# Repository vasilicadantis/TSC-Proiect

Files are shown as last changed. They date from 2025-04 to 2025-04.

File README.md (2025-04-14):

# OpenBook

Vasilica Danțiș – 332CD

## Diagrama bloc


## BOM

| Componenta | Link |
| ---| ---|
| led | [Link](https://www.snapeda.com/parts/KP-1608SURCK/Kingbright/view-part/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) |
| Button_customv1 | [Link](https://industry.panasonic.com/global/en/products/control/switch/light-touch/number/evqpuj02k) |
| Eagle_ltspice_c | [Link](https://componentsearchengine.com/part-view/0402WGF3001TCE/UNI-ROYAL(Uniroyal%20Elec)) |
| ESP32_WROVER_AVX—SD0805S020S1R0 | [Link](https://ro.mouser.com/ProductDetail/KYOCERA-AVX/SD0805S020S1R0?qs=jCA%252BPfw4LHbpkAoSnwrdjw%3D%3D) |
| ESP32_WROVER_BME680_BME680 | [Link](https://www.snapeda.com/parts/BME680/Bosch/view-part/?welcome=home) |
| ESP32_WROVER_EAGLE-LTSPICE_R | [Link](https://componentsearchengine.com/part-view/R0402%201%25%20100%20K%20(RC0402FR-07100KL)/YAGEO) |
| RCL_CPOL-EU | [Link](https://www.snapeda.com/parts/TAJB475K025RNJ/AVX/view-part/?t=capacitor%203528&con_ref=None) |
| SJ | [Link](https://grabcad.com/library/solder-jumpers-1) |
| R-URI | [Link](https://componentsearchengine.com/part-view/R0402%201%25%20100%20K%20(RC0402FR-07100KL)/YAGEO) |
| ESP32_WROVER_SPARKFUN-DISCRETESEMI_MOSFET_PCH | [Link](https://componentsearchengine.com/part-view/DMG2305UX-7/Diodes%20Incorporated) |
| ESP32_WROVER_SPARKFUN-IC-POWER_MCP73831 | [Link](https://eu.mouser.com/ProductDetail/Microchip-Technology/MCP73831T-2ACI-OT?qs=yUQqVecv4qvbBQBGbHx0Mw%3D%3D) |
| TP | Facut Manual (un cilindru) |
| FH34SRJ-24S-0.5SH_99_ | [Link](https://componentsearchengine.com/part-view/FH34SRJ-24S-0.5SH(99)/Hirose) |
| MAX17048G+T10 | [Link](https://www.snapeda.com/parts/MAX17048G+T10/Analog+Devices/view-part/) |
| SAMACSYS_PARTS_USB4110-GF-A | [Link](https://componentsearchengine.com/part-view/USB4110-GF-A/GCT%20(GLOBAL%20CONNECTOR%20TECHNOLOGY)) |
| QWIIC_CONNECTOR | [Link](https://www.snapeda.com/parts/PRT-14417/SparkFun%20Electronics/view-part/?t=QWIIC_CONNECTORJS-1MM) |
| 112A-TAAR-R03_ATTEND | [Link](https://componentsearchengine.com/part-view/112A-TAAR-R03%20ATTEND/ATTEND) |
| 744043680IND_4828-WE-TPC_WRE | [Link](https://componentsearchengine.com/part-view/744043680/W%C3%BCrth%20Elektronik) |
| BD5229G-TR | [Link](https://componentsearchengine.com/part-view/BD5229G-TR/ROHM%20Semiconductor) |
| CPH3225A | [Link](https://componentsearchengine.com/part-view/CPH3225A/Seiko%20Semiconductors) |
| DS3231SN# | [Link](https://componentsearchengine.com/part-view/DS3231SN%23/Analog%20Devices) |
| ESP32-C6-WROOM-1-N8 | [Link](https://componentsearchengine.com/part-view/ESP32-C6-WROOM-1-N8/Espressif%20Systems) |
| MBR0530 | [Link](https://componentsearchengine.com/part-view/MBR0530/onsemi) |
| SI1308EDL-T1-GE3 | [Link](https://componentsearchengine.com/part-view/SI1308EDL-T1-GE3/Vishay) |
| USBLC6-2SC6Y | [Link](https://componentsearchengine.com/part-view/USBLC6-2SC6Y/STMicroelectronics) |
| W25Q512JVEIQ | [Link](https://componentsearchengine.com/part-view/W25Q512JVEIQ/Winbond) |
| XC6220A331MR-G | [Link](https://componentsearchengine.com/part-view/XC6220A331MR-G/Torex) |

## Descriere detaliată a funcționalității hardware

1. **Microcontroller (ESP32-C6)**
   - **Rol:** Asigură controlul central al dispozitivului, conectivitatea Wi-Fi, logica de afișare pe E-Ink și interfața cu utilizatorul (butoane).
   - **Caracteristici:**
     - Integrează un nucleu RISC-V și un subsistem Wi-Fi 6 (802.11ax).
     - Consum redus în modurile de *deep-sleep*, esențial pentru un e-book reader.

2. **E-Ink Display**
   - **Tip:** (ex.) 2.9" EPD (monocrom), cu driver intern sau driver separat.
   - **Interfață cu ESP32-C6:** SPI (poate fi 4-wire SPI cu linii de comandă suplimentare: DC, CS, RST, BUSY).
   - **Motiv:** E-Ink-ul are consum redus de energie, menținând imaginea chiar și fără alimentare (refresh scăzut).

3. **Senzor BME688**
   - **Rol:** Permite ajustarea luminozității (dacă există LED) sau stocarea datelor de mediu.
   - **Interfață:** I2C (implicit) / SPI (opțional).
   - **Consum:** Relativ mic (în jur de câțiva µA în mod de stand-by, dar poate crește la câteva mA în mod de funcționare continuă).

4. **DS3231 RTC**
   - **Rol:** Asigură un ceas de timp real foarte precis, cu consum scăzut.
   - **Interfață:** I2C, cu eventual pin de interrupt (INT/SQW) pentru semnal periodic sau alarmă.
   - **Consum:** Aproximativ 1-2 µA în modul de menținere a ceasului (alimentat direct din baterie).

5. **Memorie externă NOR Flash (W25Q512)**
   - **Rol:** Oferă stocare suplimentară (ex. 64Mbit) pentru fișiere, resurse, cărți electronice etc.
   - **Interfață:** SPI la viteze ridicate (până la 40-80MHz, dacă e specificat).
   - **Consum:** Câțiva mA în scriere/citire și µA în mod standby.

6. **Sistem de alimentare și managementul bateriei**
   - **USB-C Connector:** Permite alimentare la 5V și date (pentru programare/debug).
   - **Battery Charger (MCP73831):** Încarcă Li-Po la 4.2V cu un curent setat prin rezistență PROG (ex. 500mA).
   - **LDO / DC-DC:** Convertește tensiunea bateriei (3.7V nominal) în 3.3V stabil pentru ESP32-C6, E-Ink și restul circuitelor. Dacă se dorește extragerea tensiunii de 5V, se poate folosi un boost converter (DC-DC step-up).
   - **Calcul consum (approx.):**
     - **ESP32-C6:** ~80-240 mA în mod Tx Wi-Fi, <1 mA în modem-sleep, câțiva µA în deep-sleep.
     - **E-Ink:** Consum ridicat doar la refresh (~tens of mA), inactiv aproape 0.
     - **Senzor BME688:** <1 mA tipic (pe I2C) în mod standard, <1 µA în stand-by.
     - **RTC DS3231:** 1-2 µA pentru menținerea ceasului.

7. **Interfața utilizator (Butoane)**
   - 3 butoane SMD (ex. Boot, Change, Reset) conectate la pinii GPIO ai ESP32-C6, cu rezistențe de pull-up/pull-down și debounce minimal (sau software).

8. **Alte considerații**
   - Protecție ESD pe USB, liniile SPI, conectori externi.
   - Test pad-uri: Semnalele principale (MISO, MOSI, RX, GND) expuse pentru programare / debugging.

## Detalii despre pinii ESP32-C6



## Considerații de design PCB

### Rutarea traseelor de alimentare
- Lățime de minimum **0.3 mm** pentru liniile de putere (3V3, 5V, VBAT).
- Lățime de minimum **0.15 mm** pentru liniile de date (SPI, I2C, UART etc.).
- Grosime PCB de maximum **1 mm** pentru a încăpea în carcasă.

### Decuplare
- Condensatoare de **100 nF (0402)** lângă fiecare pin de alimentare al circuitelor integrate (ESP32, BME688, DS3231, Flash).
- Condensatoare mai mari (ex. **4.7 µF ~ 10 µF**) pentru stabilizarea surselor locale.

### Antenă ESP32-C6
- Zona antenei trebuie eliberată de planul de masă și semnale, cu decupaj PCB sub antenă.

### DRC și ERC
- Verificarea regulilor de design: evitarea unghiurilor de 90°; utilizarea via stitching pe planul GND; respectarea reglementărilor de clearance etc.

### Placement
- Componentele SMD sunt plasate exclusiv pe **Top Layer** (conform specificațiilor proiectului).
- Butoanele sunt poziționate ergonomic pentru utilizator.
- Conectorul USB-C este accesibil pe marginea plăcii.

### Via Stitching
- Implementat în jurul ESP32-C6 și al planului de masă pentru reducerea zgomotului EMI.

### Test pad-uri
- Semnalele MISO, MOSI, SCK, GND, 3V3, TX, RX etc. sunt accesibile pentru programare și debugging.

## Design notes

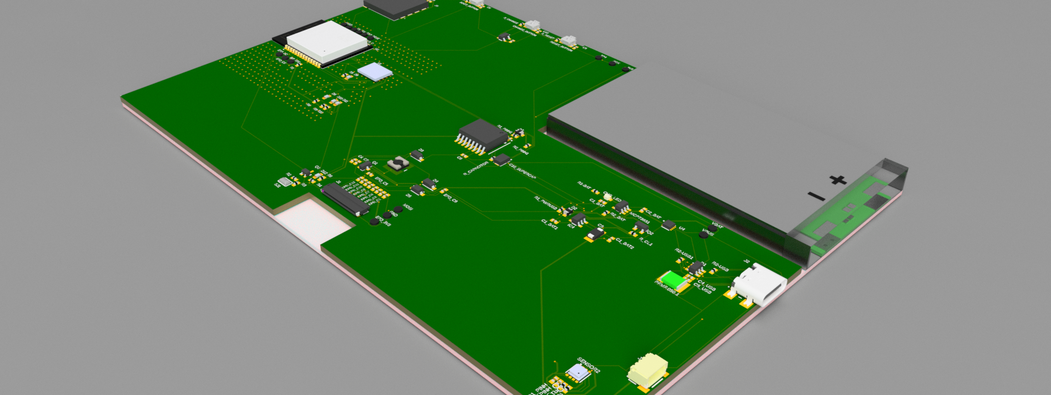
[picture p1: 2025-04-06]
Images/Battery + PCB.png

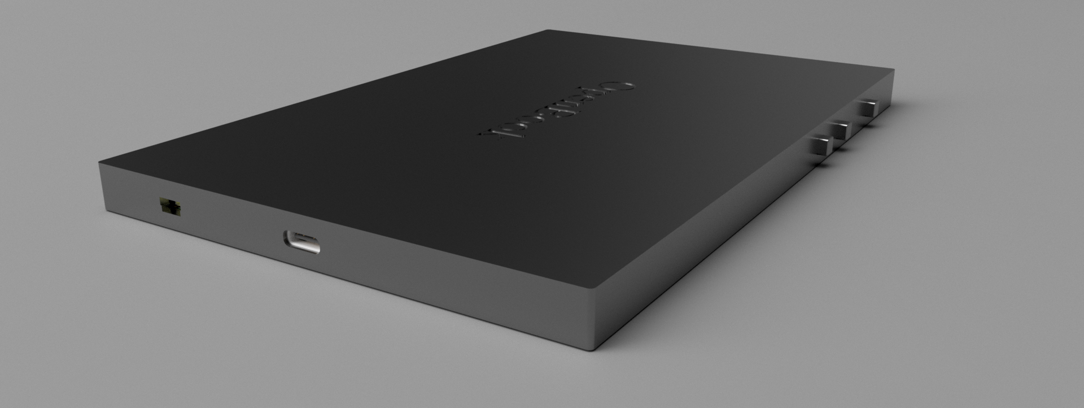
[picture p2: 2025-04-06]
Images/OpenBook - back.png

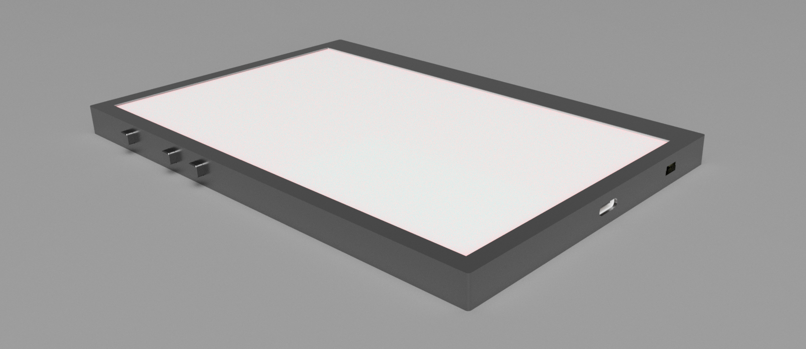
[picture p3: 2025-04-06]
Images/OpenBook - front.png

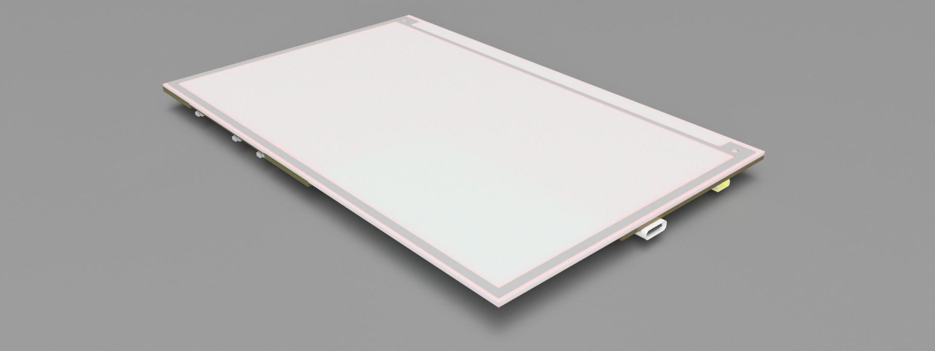
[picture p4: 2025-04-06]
Images/Display.png

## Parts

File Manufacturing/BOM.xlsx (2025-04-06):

Qty | Value | Device | Package | Parts | Description | ARROW_PART_NUMBER | ARROW_PRICE-STOCK | AVAILABILITY | CENTROID_NOT_SPECIFIED | CHECK_PRICES | COPYRIGHT | DATASHEET | DESCRIPTION | DIGIKEY_DESCRIPTION | DIGIKEY_PART_NUMBER | HEIGHT | LEAD_FREE | MANUFACTURER_NAME | MANUFACTURER_PART_NUMBER | MF | MFR_NAME | MOUSER_PART_NUMBER | MOUSER_PRICE-STOCK | MOUSER_TESTING_PART_NUMBER | MOUSER_TESTING_PRICE-STOCK | MP | MPN | PACKAGE | POPULARITY | PREFIX | PRICE | PROD_ID | PURCHASE-URL | ROHS | SNAPEDA_LINK | SPICEMODEL | SPICEPREFIX | TEMPERATURE_RANGE_HIGH | TEMPERATURE_RANGE_LOW | TP_SIGNAL_NAME | VALUE
1 |  | ADAFRUIT_LEDCHIP-LED0603 | ADAFRUIT_CHIP-LED0603 | CHG_LED | LED
1 |  | SJ | SJ | SJ1 | SMD solder JUMPER |  |  |  |  |  |  |  |  |  |  |  |  |  |  |  |  |  |  |  |  |  |  |  | 3
1 | 0.47 | ESP32_WROVER_EAGLE-LTSPICE_RR0402 | ESP32_WROVER_EAGLE-LTSPICE_R0402 | R3 | RESISTOR, European symbol |  |  |  |  |  |  |  |  |  |  |  |  |  |  |  |  |  |  |  |  |  |  |  |  |  |  |  |  |  |  | NONE | R
1 | 100K | ESP32_WROVER_EAGLE-LTSPICE_RR0402 | ESP32_WROVER_EAGLE-LTSPICE_R0402 | R1_PWRUSB | RESISTOR, European symbol |  |  |  |  |  |  |  |  |  |  |  |  |  |  |  |  |  |  |  |  |  |  |  |  |  |  |  |  |  |  | NONE | R
8 | 100nF | ESP32_WROVER_EAGLE-LTSPICE_CC0402 | ESP32_WROVER_EAGLE-LTSPICE_C0402 | C1, C2, C4_USB, C6, C8, C9, C10, C_DELAY | CAPACITOR, European symbol |  |  |  |  |  |  |  |  |  |  |  |  |  |  |  |  |  |  |  |  |  |  |  |  |  |  |  |  |  |  | NONE | C
1 | 100uF | RCL_CPOL-EUCT3528 | RCL_CT3528 | C3 | POLARIZED CAPACITOR, European symbol |  |  |  |  |  |  |  |  |  |  |  |  |  |  |  |  |  |  |  |  |  |  |  | 0 |  |  |  |  |  |  |  | C
14 | 10K | ESP32_WROVER_EAGLE-LTSPICE_RR0402 | ESP32_WROVER_EAGLE-LTSPICE_R0402 | R1_PINH, R1_PINH1, R2_PINH, R2_PINH1, R5, R6, R7, R8, R9, R10, R_BOOT, R_CHANGE, R_CL1, R_RESET | RESISTOR, European symbol |  |  |  |  |  |  |  |  |  |  |  |  |  |  |  |  |  |  |  |  |  |  |  |  |  |  |  |  |  |  | NONE | R
2 | 10k | ESP32_WROVER_EAGLE-LTSPICE_RR0402 | ESP32_WROVER_EAGLE-LTSPICE_R0402 | R1, R4 | RESISTOR, European symbol |  |  |  |  |  |  |  |  |  |  |  |  |  |  |  |  |  |  |  |  |  |  |  |  |  |  |  |  |  |  | NONE | R
1 | 10uF | ESP32_WROVER_EAGLE-LTSPICE_CC0402 | ESP32_WROVER_EAGLE-LTSPICE_C0402 | C7 | CAPACITOR, European symbol |  |  |  |  |  |  |  |  |  |  |  |  |  |  |  |  |  |  |  |  |  |  |  |  |  |  |  |  |  |  | NONE | C
1 | 112A-TAAR-R03_ATTEND | 112A-TAAR-R03_ATTEND | 112ATAARR03ATTEND | J4 | Micro SD Card Socket, Push-Push Type, Top Mount, SMT, H=1.83mm, 10u |  |  |  |  |  |  |  | Micro SD Card Socket | Push-Push Type | Top Mount | SMT | H=1.83mm | 10u |  |  | 1.9mm |  | ATTEND | 112A-TAAR-R03 ATTEND
1 | 15 | ESP32_WROVER_EAGLE-LTSPICE_RR0402 | ESP32_WROVER_EAGLE-LTSPICE_R0402 | R_CAPACITOR | RESISTOR, European symbol |  |  |  |  |  |  |  |  |  |  |  |  |  |  |  |  |  |  |  |  |  |  |  |  |  |  |  |  |  |  | NONE | R
1 | 1uF | ESP32_WROVER_EAGLE-LTSPICE_CC0402 | ESP32_WROVER_EAGLE-LTSPICE_C0402 | C5 | CAPACITOR, European symbol |  |  |  |  |  |  |  |  |  |  |  |  |  |  |  |  |  |  |  |  |  |  |  |  |  |  |  |  |  |  | NONE | C
10 | 1uF/50V | ESP32_WROVER_EAGLE-LTSPICE_CC0402 | ESP32_WROVER_EAGLE-LTSPICE_C0402 | EPD_C1, EPD_C2, EPD_C5, EPD_C6, EPD_C7, EPD_C8, EPD_C9, EPD_C10, EPD_C11, EPD_C12 | CAPACITOR, European symbol |  |  |  |  |  |  |  |  |  |  |  |  |  |  |  |  |  |  |  |  |  |  |  |  |  |  |  |  |  |  | NONE | C
1 | 2.2 | ESP32_WROVER_EAGLE-LTSPICE_RR0402 | ESP32_WROVER_EAGLE-LTSPICE_R0402 | R2 | RESISTOR, European symbol |  |  |  |  |  |  |  |  |  |  |  |  |  |  |  |  |  |  |  |  |  |  |  |  |  |  |  |  |  |  | NONE | R
1 | 200 | ESP32_WROVER_EAGLE-LTSPICE_RR0402 | ESP32_WROVER_EAGLE-LTSPICE_R0402 | R1-BAT | RESISTOR, European symbol |  |  |  |  |  |  |  |  |  |  |  |  |  |  |  |  |  |  |  |  |  |  |  |  |  |  |  |  |  |  | NONE | R
2 | 20V/4.2A/52mO/1.4W | ESP32_WROVER_SPARKFUN-DISCRETESEMI_MOSFET_PCH-DMG2305UX-7 | ESP32_WROVER_SPARKFUN-DISCRETESEMI_SOT23-3 | Q1, Q2 | P-channel MOSFETs |  |  |  |  |  |  |  |  |  |  |  |  |  |  |  |  |  |  |  |  |  |  |  |  |  |  | TRAN-14388 |  |  |  |  |  |  |  |  | 20V/4.2A/52mO/1.4W
1 | 2K | ESP32_WROVER_EAGLE-LTSPICE_RR0402 | ESP32_WROVER_EAGLE-LTSPICE_R0402 | R2_BAT | RESISTOR, European symbol |  |  |  |  |  |  |  |  |  |  |  |  |  |  |  |  |  |  |  |  |  |  |  |  |  |  |  |  |  |  | NONE | R
1 | 4.7UF | ESP32_WROVER_EAGLE-LTSPICE_CC0402 | ESP32_WROVER_EAGLE-LTSPICE_C0402 | C2_BAT | CAPACITOR, European symbol |  |  |  |  |  |  |  |  |  |  |  |  |  |  |  |  |  |  |  |  |  |  |  |  |  |  |  |  |  |  | NONE | C
4 | 4.7uF | ESP32_WROVER_EAGLE-LTSPICE_CC0402 | ESP32_WROVER_EAGLE-LTSPICE_C0402 | C1_BAT, C1_BAT1, C1_BAT2, C5_USB | CAPACITOR, European symbol |  |  |  |  |  |  |  |  |  |  |  |  |  |  |  |  |  |  |  |  |  |  |  |  |  |  |  |  |  |  | NONE | C
1 | 4.7uF/25V | ESP32_WROVER_EAGLE-LTSPICE_CC0402 | ESP32_WROVER_EAGLE-LTSPICE_C0402 | C4 | CAPACITOR, European symbol |  |  |  |  |  |  |  |  |  |  |  |  |  |  |  |  |  |  |  |  |  |  |  |  |  |  |  |  |  |  | NONE | C
2 | 5K1 | ESP32_WROVER_EAGLE-LTSPICE_RR0402 | ESP32_WROVER_EAGLE-LTSPICE_R0402 | R2-USB, R2-USB1 | RESISTOR, European symbol |  |  |  |  |  |  |  |  |  |  |  |  |  |  |  |  |  |  |  |  |  |  |  |  |  |  |  |  |  |  | NONE | R
1 | 68uH | 744043680IND_4828-WE-TPC_WRE | IND_4828-WE-TPC_WRE | L1 |  |  |  |  |  |  | Copyright (C) 2024 Ultra Librarian. All rights reserved. |  |  |  |  |  |  |  | 744043680 |  | Wurth Electronics
1 | BD5229G-TR | BD5229G-TR | SOT95P280X120-5N | IC1 | Voltage Detector with Adjustable Delay Time: CMOS processes are utilized to develop high precision, low current consumption CMOS reset ICs that allow arbitrary setting of the delay time. The extensive lineup includes both Nch Open Drain and CMOS output types in a wide range of detection voltages (from 2.3V to 6.0V, in 0.1V steps), enabling selection of the ideal solution based on customer requirements. In addition, the entire series is of course both lead-free and RoHS-compliant. |  |  |  |  |  |  |  | Voltage Detector with Adjustable Delay Time: CMOS processes are utilized to develop high precision | low current consumption CMOS reset ICs that allow arbitrary setting of the delay time. The extensive lineup includes both Nch Open Drain and CMOS output types in a wide range of detection voltages (from 2.3V to 6.0V | in 0.1V steps) | enabling selection of the ideal solution based on customer requirements. In addition | the entire series is of course both lead-free and RoHS-compliant. |  |  | 1.25mm |  | ROHM Semiconductor | BD5229G-TR |  |  | 755-BD5229G-TR | https://www.mouser.co.uk/ProductDetail/ROHM-Semiconductor/BD5229G-TR?qs=4kLU8WoGk0vvnhrrYwdszw%3D%3D
3 | BUTTON_CUSYOMV1 | BUTTON_CUSYOMV1 | MYBUTTON | BOOT_BUTTON, CHANGE_BUTTON, RESET_BUTTON
1 | CPH3225A | CPH3225A | CAPCP3225X100N | C10_SUPERCAP | Cap 0.011F 3.3V 1210 Flat Check availability |  |  | Not in stock |  | https://www.snapeda.com/parts/CPH3225A/Seiko+Instruments/view-part/?ref=eda |  |  | 11 mF (EDLC) Supercapacitor 3.3 V 1210 (3225 Metric) - - |  |  |  |  |  |  | Seiko Instruments |  |  |  |  |  | CPH3225A |  | 1210 Seiko |  |  | None |  | https://www.snapeda.com/api/url_track_click_mouser/?unipart_id=562593&manufacturer=Seiko Instruments&part_name=CPH3225A&search_term=None |  | https://www.snapeda.com/parts/CPH3225A/Seiko+Instruments/view-part/?ref=snap
1 | DS3231SN# | DS3231SN# | SOIC127P1032X265-16N | U3 | Real Time Clock Serial 16-Pin SOIC W T/R Check availability |  |  | In Stock |  | https://www.snapeda.com/parts/DS3231SN%23/Analog+Devices/view-part/?ref=eda |  |  | Extremely Accurate I²C-Integrated RTC/TCXO/Crystal |  |  |  |  |  |  | Analog Devices |  |  |  |  |  | DS3231SN# |  | SOIC-16 Maxim |  |  | None |  | https://www.snapeda.com/api/url_track_click_mouser/?unipart_id=99048&manufacturer=Analog Devices&part_name=DS3231SN#&search_term=None |  | https://www.snapeda.com/parts/DS3231SN%23/Analog+Devices/view-part/?ref=snap
1 | ESP32-C6-WROOM-1-N8 | ESP32-C6-WROOM-1-N8 | XCVR_ESP32-C6-WROOM-1-N8 | U2 | Check availability |  |  | In Stock |  | https://www.snapeda.com/parts/ESP32-C6-WROOM-1-N8/Espressif+Systems/view-part/?ref=eda |  |  | Multiprotocol Modules ESP32-C6 module | Wi-Fi 6 in 2.4 GHz band | Bluetooth 5 | Zigbee 3.0 and Thread. ESP34-WROOM Compatible - ENGINEERING SAMPLE |  |  |  |  |  |  | Espressif Systems |  |  |  |  |  | ESP32-C6-WROOM-1-N8 |  | None |  |  | None |  |  |  | https://www.snapeda.com/parts/ESP32-C6-WROOM-1-N8/Espressif+Systems/view-part/?ref=snap
1 | ESP32C6_VARISTORCN1812 | ESP32C6_VARISTORCN1812 | ESP32C6_VARISTOR_CT/CN1812 | PFMF.050.1 | VARISTOR |  |  |  |  |  |  |  |  |  |  |  |  |  |  |  |  |  |  |  |  |  |  |  | 0
2 | ESP32_WROVER_AVX---SD0805S020S1R0_AVX_SD0805S020S1R0_0_0AVX_SD0805S020S1R0_0_0 | ESP32_WROVER_AVX---SD0805S020S1R0_AVX_SD0805S020S1R0_0_0AVX_SD0805S020S1R0_0_0 | ESP32_WROVER_AVX---SD0805S020S1R0_AVX_SD0805S020S1R0_0 | D2, D7 | Schottky Barrier Rectifier Diode |  |  |  | No |  |  | http://datasheets.avx.com/schottky.pdf |  | DIODE SCHOTTKY 20V 1A 0805 | 478-7800-1-ND |  | yes |  |  | AVX |  | 581-SD0805S020S1R0 |  |  |  |  |  | 0805 (2012 metric) |  | D |  |  |  | yes |  |  |  | +125°C | -55°C
1 | ESP32_WROVER_BME680_BME680 | ESP32_WROVER_BME680_BME680 | ESP32_WROVER_BME680_PSON80P300X300X100-8N | SENSOR2 | Integrated Environmental Unit |  |  | Unavailable |  |  |  |  | Integrated Environmental Unit |  |  |  |  |  |  | Bosch Sensortec |  |  |  |  |  | BME680 |  | LGA-8 Bosch Tools |  |  | None
1 | ESP32_WROVER_SPARKFUN-IC-POWER_MCP73831 | ESP32_WROVER_SPARKFUN-IC-POWER_MCP73831 | ESP32_WROVER_SPARKFUN-IC-POWER_SOT23-5 | MCP73831 | MCP73831T Li-Ion, Li-Pol Controller |  |  |  |  |  |  |  |  |  |  |  |  |  |  |  |  |  |  |  |  |  |  |  |  |  |  | IC-09995
1 | FH34SRJ-24S-0.5SH_99_ | FH34SRJ-24S-0.5SH_99_ | FH34SRJ24S05SH99 | J1 | (0.50mm) Surface Mount, Right Angle |  |  |  |  |  |  |  | 24 Position FFC | FPC Connector Contacts | (0.50mm) Surface Mount | Right Angle |  |  | 1.1mm |  | Hirose | FH34SRJ-24S-0.5SH(99) |  |  | 798-FH34SRJ24S05SH99 | https://www.mouser.co.uk/ProductDetail/Hirose-Connector/FH34SRJ-24S-0.5SH99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
1 | MAX17048G+T10 | MAX17048G+T10 | SON50P200X200X80-9N | U4 | Check availability |  |  | In Stock |  | https://www.snapeda.com/parts/MAX17048G+T10/Analog+Devices/view-part/?ref=eda |  |  | 3µA 1-Cell/2-Cell Fuel Gauge with ModelGauge |  |  |  |  |  |  | Analog Devices |  |  |  |  |  | MAX17048G+T10 |  | TDFN-8 Maxim |  |  | None |  | https://www.snapeda.com/api/url_track_click_mouser/?unipart_id=329239&manufacturer=Analog Devices&part_name=MAX17048G+T10&search_term=None |  | https://www.snapeda.com/parts/MAX17048G+T10/Analog+Devices/view-part/?ref=snap
3 | MBR0530 | MBR0530 | SOD3716X135N | D3, D4, D5 | ON SEMICONDUCTOR - MBR0530 - DIODE, SCHOTTKY, 0.5A, 30V, SOD-123 |  |  | In Stock |  | https://www.snapeda.com/parts/MBR0530/Onsemi/view-part/?ref=eda |  |  | Diode Schottky 30 V 500mA Surface Mount SOD-123 |  |  |  |  |  |  | ON Semiconductor |  |  |  |  |  | MBR0530 |  | SOD-123-2 ON Semiconductor |  |  | None |  | https://www.snapeda.com/api/url_track_click_mouser/?unipart_id=179458&manufacturer=ON Semiconductor&part_name=MBR0530&search_term=None |  | https://www.snapeda.com/parts/MBR0530/Onsemi/view-part/?ref=snap
6 | PGB1010603MR | PGB1010603MR | DIOC1608X36N | D6, D8, D9, D10, D11, D12 | Check availability |  |  | In Stock |  | https://www.snapeda.com/parts/PGB1010603MR/Littelfuse/view-part/?ref=eda |  |  | 150V (Typ) Clamp - Ipp Tvs Diode Surface Mount 0603 (1608 Metric) |  |  |  |  |  |  | Littelfuse Inc. |  |  |  |  |  | PGB1010603MR |  | 0603 Littelfuse Inc. |  |  | None |  | https://www.snapeda.com/api/url_track_click_mouser/?unipart_id=5659453&manufacturer=Littelfuse Inc.&part_name=PGB1010603MR&search_term=None |  | https://www.snapeda.com/parts/PGB1010603MR/Littelfuse/view-part/?ref=snap
1 | QWIIC_RIGHT_ANGLE | QWIIC_CONNECTORJS-1MM | JST04_1MM_RA | J3 | SparkFun I2C Standard Qwiic Connector |  |  |  |  |  |  |  |  |  |  |  |  |  |  |  |  |  |  |  |  |  |  |  |  |  |  | CONN-13694 |  |  |  |  |  |  |  |  | QWIIC_RIGHT_ANGLE
1 | SAMACSYS_PARTS_USB4110-GF-A | SAMACSYS_PARTS_USB4110-GF-A | SAMACSYS_PARTS_USB4110GFA | J2 | CONN USB 2.0 TYPE-C R/A SMT |  |  |  |  |  |  |  | CONN USB 2.0 TYPE-C R/A SMT |  |  | 3.26mm |  | GCT (GLOBAL CONNECTOR TECHNOLOGY) | USB4110-GF-A |  |  | 640-USB4110-GF-A | https://www.mouser.co.uk/ProductDetail/GCT/USB4110-GF-A?qs=KUoIvG%2F9IlYiZvIXQjyJeA%3D%3D
1 | SI1308EDL-T1-GE3 | SI1308EDL-T1-GE3 | SOT65P210X110-3N | Q3 | MOSFET N-Ch 30V 1.5A TrenchFET SC70 Vishay Si1308EDL-T1-GE3 N-channel MOSFET Transistor, 1.5 A, 30 V, 3-Pin SC-70 |  |  | In Stock |  | https://www.snapeda.com/parts/SI1308EDL-T1-GE3/Vishay+Siliconix/view-part/?ref=eda |  |  | Si1308EDL-T1-GE3 N-channel MOSFET Transistor | 1.5 A | 30 V | 3-Pin SC-70 | Siliconix / Vishay SI1308EDL-T1-GE3 |  |  |  |  |  |  | Vishay Siliconix |  |  |  |  |  | SI1308EDL-T1-GE3 |  | SOT-323 Vishay Semiconductor |  |  | None |  | https://www.snapeda.com/api/url_track_click_mouser/?unipart_id=274603&manufacturer=Vishay Siliconix&part_name=SI1308EDL-T1-GE3&search_term=None |  | https://www.snapeda.com/parts/SI1308EDL-T1-GE3/Vishay+Siliconix/view-part/?ref=snap
17 | TPTP20R | TPTP20R | TP20R | 3V3, EDP_RESE, EPD_3V3, EPD_3V3_C, EPD_BUSY, EPD_CS, EPD_DC, GND, INT_RTC, MISO, MOSI, RX, SCK, TP4, TX, VBAT, VBUS | Test pad |  |  |  |  |  |  |  |  |  |  |  |  |  |  |  |  |  |  |  |  |  |  |  | 2
1 | USBLC6-2SC6Y | USBLC6-2SC6Y | SOT95P280X145-6N | D1 | Low Cap. ESD Protection Auto SOT-23-6 STMicroelectronics USBLC6-2SC6Y, Dual Uni-Directional TVS Diode Array, 6-Pin SOT-23 |  |  | In Stock |  | https://www.snapeda.com/parts/USBLC6-2SC6Y/STMicroelectronics/view-part/?ref=eda |  |  | 17V Clamp 5A (8/20µs) Ipp Tvs Diode Surface Mount SOT-23-6 |  |  |  |  |  |  | STMicroelectronics |  |  |  |  |  | USBLC6-2SC6Y |  | SOT-23-6 STMicroelectronics |  |  | None |  |  |  | https://www.snapeda.com/parts/USBLC6-2SC6Y/STMicroelectronics/view-part/?ref=snap
1 | W25Q512JVEIQ | W25Q512JVEIQ | SON127P600X800X80-9N | U1 | Check availability |  |  | In Stock |  | https://www.snapeda.com/parts/W25Q512JVEIQ/Winbond+Electronics/view-part/?ref=eda |  |  | FLASH - NOR Memory IC 512Mb (64M x 8) SPI - Quad I/O 133 MHz 8-WSON (8x6) |  |  |  |  |  |  | Winbond Electronics |  |  |  |  |  | W25Q512JVEIQ |  | Package |  |  | None |  |  |  | https://www.snapeda.com/parts/W25Q512JVEIQ/Winbond+Electronics/view-part/?ref=snap
1 | XC6220A331MR-G | XC6220A331MR-G | SOT95P280X120-5N | IC4 | LDO Voltage Regulators |  |  |  |  |  |  |  | LDO Voltage Regulators |  |  | 1.2mm |  | Torex | XC6220A331MR-G |  |  | 865-XC6220A331MR-G | https://www.mouser.co.uk/ProductDetail/Torex-Semiconductor/XC6220A331MR-G?qs=AsjdqWjXhJ8ZSWznL1J0gg%3D%3D

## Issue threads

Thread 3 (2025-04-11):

Ground plane PCB

alexiaenache, 2025-04-11:
**Issue**
* [ ]  Ground planeurile nu ar trebui sa aiba inconsistente in conectare.

**Reproduce**

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

**Fixes and suggestions**
Foloseste via stitching sa conectezi planurile
Ai grija ca stitchingul sa nu deconecteze alte fire sau sa nu creeaze alte gauri in ground plane.

Closed 2025-04-14.

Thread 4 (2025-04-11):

PCB depth

alexiaenache, 2025-04-11:
**Issue**
* [ ] Modifica grosimea placii la 1mm, acum pare ca e 1.6mm.

**Reproduce**

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

**Fixes and Suggestions**

Modifica design - layers - layes stack - edit material properties.

Closed 2025-04-14.

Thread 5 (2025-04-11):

Layerul pentru masuratori

alexiaenache, 2025-04-11:
**Issue**
* [ ]  Masuratorile ar trebui sa fie toate pe layerul dimensions.

**Reproduce**

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

**Fixes and suggestions**
Schimba layerul la celelalte masuratori pe langa cea de sus sa fie tot pe layerul dimensions.

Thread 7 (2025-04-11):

Small 3D components placement issues

alexiaenache, 2025-04-11:
**Issue**
* [ ]  2 piese sunt amplasate putin mai sus decat pinii de pe placa, nefacand contact. Ar trebui mutate pe pini.
* [ ]  o piesa are un conector putin in afara pinului

**Reproduce**

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

**Fixes and suggestions**
Muta piesele in Edit component 3D sa se afle pe modelul trasat pentru pini.

Closed 2025-04-14.

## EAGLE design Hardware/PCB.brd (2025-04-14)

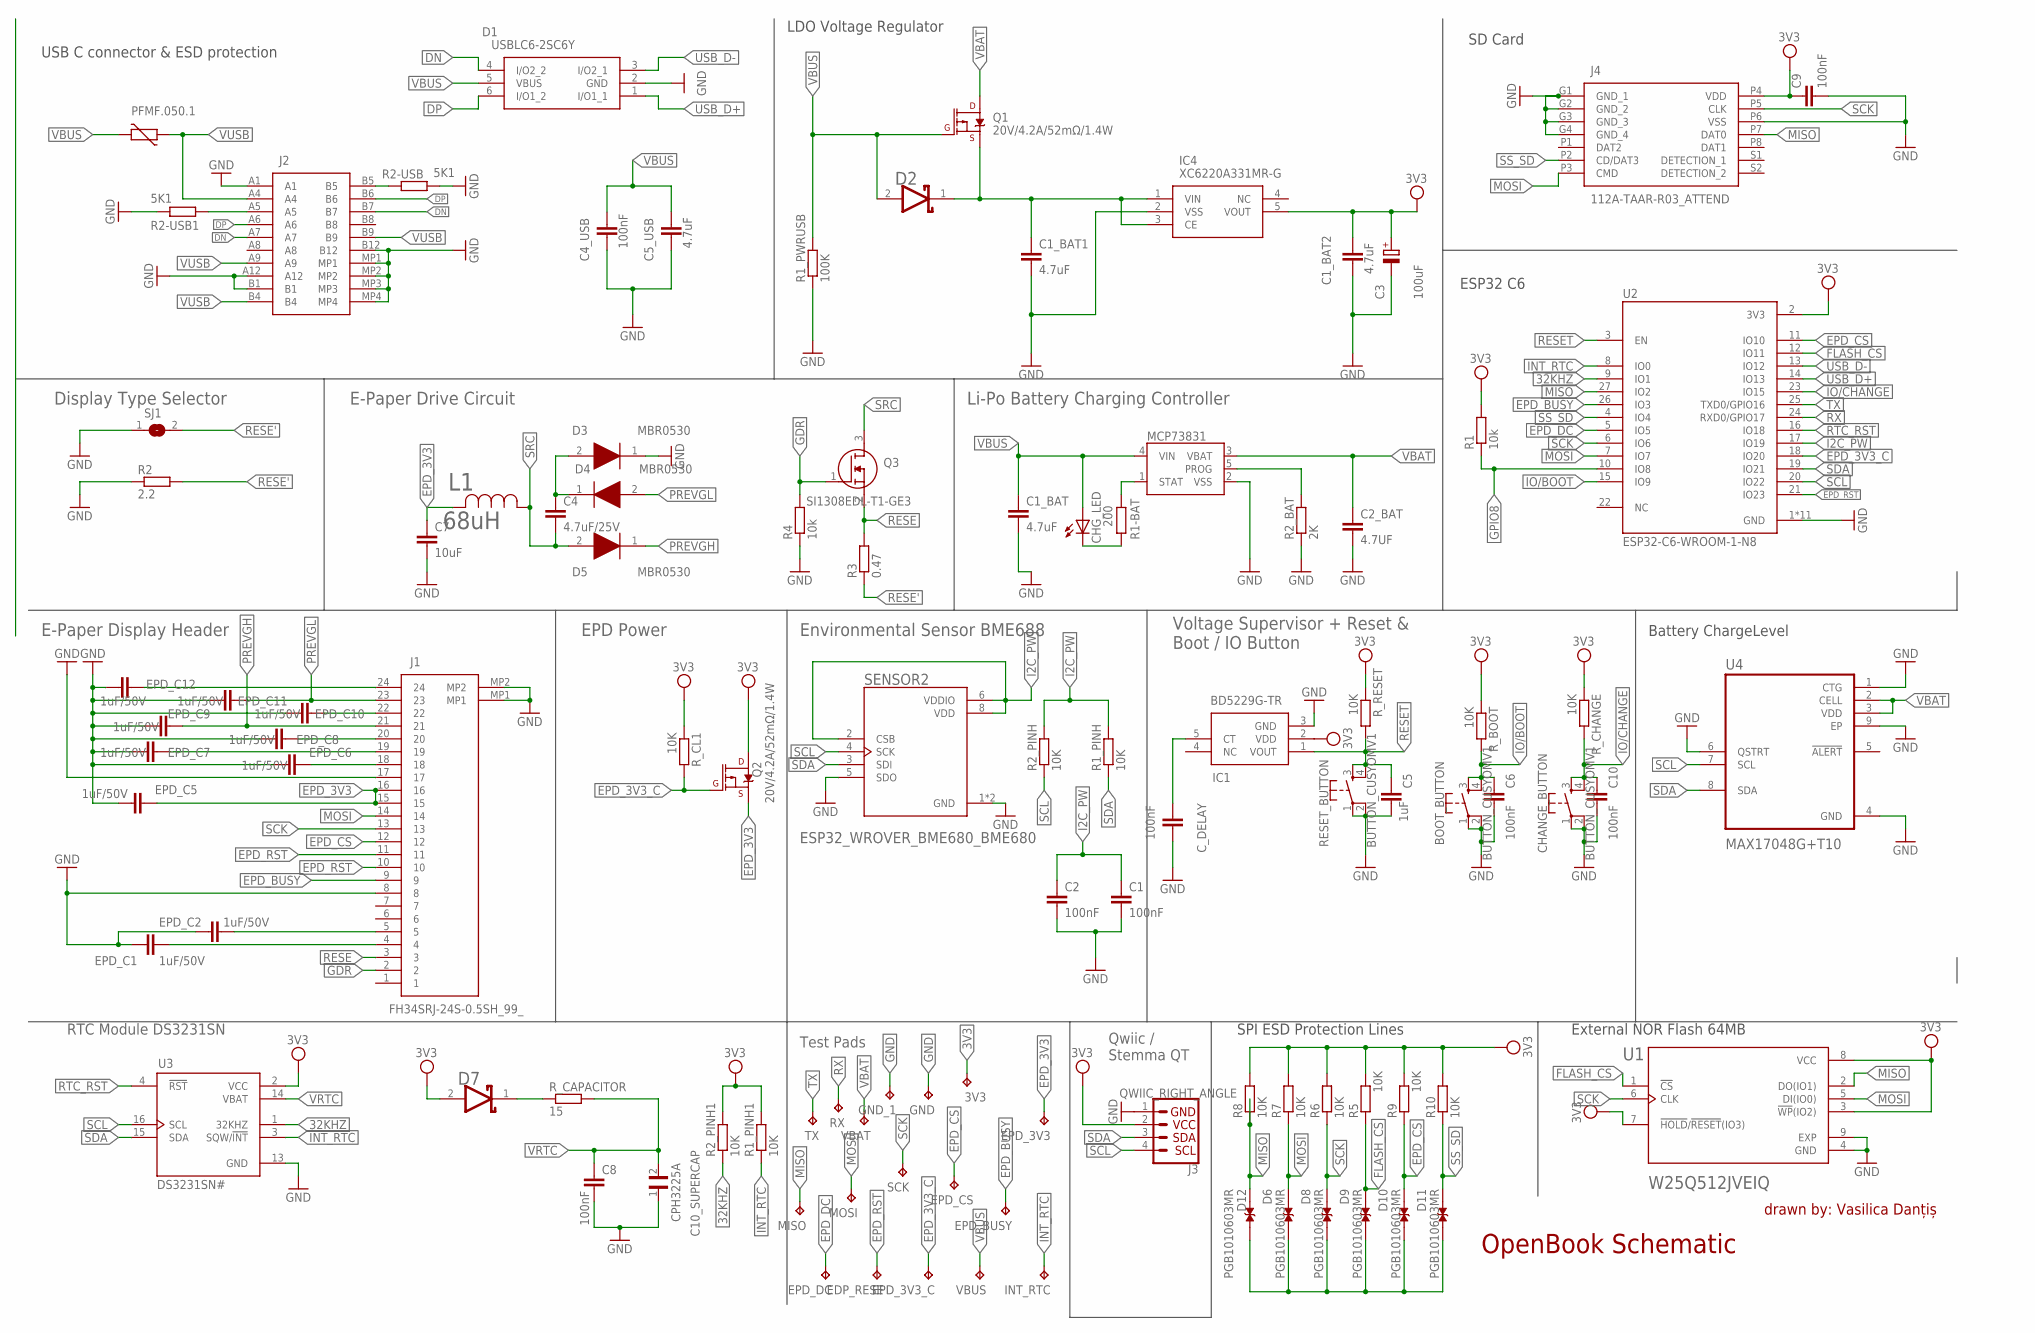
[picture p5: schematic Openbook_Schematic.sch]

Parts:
3V3: TPTP20R; TP20R
BOOT_BUTTON: BUTTON_CUSYOMV1; MYBUTTON
C1, C2, C4_USB, C6, C8, C9, C10: 100nF; ESP32_WROVER_EAGLE-LTSPICE_C0402
C1_BAT, C1_BAT1, C1_BAT2, C5_USB: 4.7uF; ESP32_WROVER_EAGLE-LTSPICE_C0402
C2_BAT: 4.7UF; ESP32_WROVER_EAGLE-LTSPICE_C0402
C3: 100uF; RCL_CT3528
C4: 4.7uF/25V; ESP32_WROVER_EAGLE-LTSPICE_C0402
C5: 1uF; ESP32_WROVER_EAGLE-LTSPICE_C0402
C7: 10uF; ESP32_WROVER_EAGLE-LTSPICE_C0402
C10_SUPERCAP: CPH3225A; CAPCP3225X100N
CHANGE_BUTTON: BUTTON_CUSYOMV1; MYBUTTON
CHG_LED: ADAFRUIT_LEDCHIP-LED0603; ADAFRUIT_CHIP-LED0603
C_DELAY: 100nF; ESP32_WROVER_EAGLE-LTSPICE_C0402
D1: USBLC6-2SC6Y; SOT95P280X145-6N
D2, D7: ESP32_WROVER_AVX---SD0805S020S1R0_AVX_SD0805S020S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; ESP32_WROVER_AVX---SD0805S020S1R0_AVX_SD0805S020S1R0_0
D3, D4, D5: MBR0530; SOD3716X135N
D6, D8, D9, D10, D11, D12: PGB1010603MR; DIOC1608X36N
EDP_RESE: TPTP20R; TP20R
EPD_3V3, EPD_3V3_C: TPTP20R; TP20R
EPD_BUSY: TPTP20R; TP20R
EPD_C1, EPD_C2, EPD_C5, EPD_C6, EPD_C7, EPD_C8, EPD_C9, EPD_C10, EPD_C11, EPD_C12: 1uF/50V; ESP32_WROVER_EAGLE-LTSPICE_C0402
EPD_CS: TPTP20R; TP20R
EPD_DC: TPTP20R; TP20R
GND: TPTP20R; TP20R
GND_1: TPTP20R; TP20R
IC1: BD5229G-TR; SOT95P280X120-5N
IC4: XC6220A331MR-G; SOT95P280X120-5N
INT_RTC: TPTP20R; TP20R
J1: FH34SRJ-24S-0.5SH_99_; FH34SRJ24S05SH99
J2: SAMACSYS_PARTS_USB4110-GF-A; SAMACSYS_PARTS_USB4110GFA
J3: QWIIC_RIGHT_ANGLE; JST04_1MM_RA
J4: 112A-TAAR-R03_ATTEND; 112ATAARR03ATTEND
L1: 68uH; IND_4828-WE-TPC_WRE
MCP73831: ESP32_WROVER_SPARKFUN-IC-POWER_MCP73831; ESP32_WROVER_SPARKFUN-IC-POWER_SOT23-5
MISO: TPTP20R; TP20R
MOSI: TPTP20R; TP20R
PFMF.050.1: ESP32C6_VARISTORCN1812; ESP32C6_VARISTOR_CT/CN1812
Q1, Q2: 20V/4.2A/52mΩ/1.4W; ESP32_WROVER_SPARKFUN-DISCRETESEMI_SOT23-3
Q3: SI1308EDL-T1-GE3; SOT65P210X110-3N
R1, R4: 10k; ESP32_WROVER_EAGLE-LTSPICE_R0402
R1-BAT: 200; ESP32_WROVER_EAGLE-LTSPICE_R0402
R1_PINH, R1_PINH1, R2_PINH, R2_PINH1, R5, R6, R7, R8, R9, R10: 10K; ESP32_WROVER_EAGLE-LTSPICE_R0402
R1_PWRUSB: 100K; ESP32_WROVER_EAGLE-LTSPICE_R0402
R2: 2.2; ESP32_WROVER_EAGLE-LTSPICE_R0402
R2-USB, R2-USB1: 5K1; ESP32_WROVER_EAGLE-LTSPICE_R0402
R2_BAT: 2K; ESP32_WROVER_EAGLE-LTSPICE_R0402
R3: 0.47; ESP32_WROVER_EAGLE-LTSPICE_R0402
RESET_BUTTON: BUTTON_CUSYOMV1; MYBUTTON
RX: TPTP20R; TP20R
R_BOOT: 10K; ESP32_WROVER_EAGLE-LTSPICE_R0402
R_CAPACITOR: 15; ESP32_WROVER_EAGLE-LTSPICE_R0402
R_CHANGE: 10K; ESP32_WROVER_EAGLE-LTSPICE_R0402
R_CL1: 10K; ESP32_WROVER_EAGLE-LTSPICE_R0402
R_RESET: 10K; ESP32_WROVER_EAGLE-LTSPICE_R0402
SCK: TPTP20R; TP20R
SENSOR2: ESP32_WROVER_BME680_BME680; ESP32_WROVER_BME680_PSON80P300X300X100-8N
SJ1: SJ
TX: TPTP20R; TP20R
U1: W25Q512JVEIQ; SON127P600X800X80-9N
U2: ESP32-C6-WROOM-1-N8; XCVR_ESP32-C6-WROOM-1-N8
U3: DS3231SN#; SOIC127P1032X265-16N
U4: MAX17048G+T10; SON50P200X200X80-9N
VBAT: TPTP20R; TP20R
VBUS: TPTP20R; TP20R

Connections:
3V3: 3V3.TP, C1_BAT2.1, C3.+, C9.1, D7.2 (ANODE), IC1.2 (VDD), IC4.5 (VOUT), J3.2, J4.P4 (VDD), Q2.3 (D), R1.2, R1_PINH1.2, R2_PINH1.2, R5.2, R6.2, R7.2, R8.2, R9.2, R10.2, R_BOOT.1, R_CHANGE.1, R_CL1.1, R_RESET.1, U1.3 (!WP!(IO2)), U1.7 (!HOLD!/!RESET!(IO3)), U1.8 (VCC), U2.2 (3V3), U3.2 (VCC)
32KHZ: R2_PINH1.1, U2.9 (IO1), U3.1 (32KHZ)
DN: D1.4 (I/O2_2), J2.A7, J2.B7
DP: D1.6 (I/O1_2), J2.A6, J2.B6
EPD_3V3: C7.1, EPD_3V3.TP, EPD_C5.1, J1.15, J1.16, L1.2, Q2.2 (S)
EPD_3V3_C: EPD_3V3_C.TP, Q2.1 (G), R_CL1.2, U2.18 (IO20)
EPD_BUSY: EPD_BUSY.TP, J1.9, U2.26 (IO3)
EPD_CS: D10.1, EPD_CS.TP, J1.12, R9.1, U2.11 (IO10)
EPD_DC: EPD_DC.TP, U2.5 (IO5)
EPD_RST: EDP_RESE.TP, J1.10, J1.11, U2.21 (IO23)
FLASH_CS: D9.1, R5.1, U1.1 (!CS), U2.12 (IO11)
GDR: J1.2, Q3.1 (G), R4.2
GND: BOOT_BUTTON.1, BOOT_BUTTON.2, C1.2, C1_BAT.2, C1_BAT1.2, C1_BAT2.2, C2.2, C2_BAT.2, C3.-, C4_USB.2, C5.2, C5_USB.2, C6.2, C7.2, C8.2, C9.2, C10.2, C10_SUPERCAP.1, CHANGE_BUTTON.1, CHANGE_BUTTON.2, C_DELAY.2, D1.2 (GND), D3.1 (K), EPD_C1.2, EPD_C2.2, EPD_C5.2, EPD_C6.2, EPD_C7.2, EPD_C8.2, EPD_C9.2, EPD_C10.2, EPD_C11.2, EPD_C12.2, GND.TP, GND_1.TP, IC1.3 (GND), IC4.2 (VSS), J1.8, J1.17, J1.MP1, J1.MP2, J2.A1, J2.A12, J2.B1, J2.B12, J2.MP1, J2.MP2, J2.MP3, J2.MP4, J3.1, J4.G1 (GND_1), J4.G2 (GND_2), J4.G3 (GND_3), J4.G4 (GND_4), J4.P6 (VSS), MCP73831.2 (VSS), R1_PWRUSB.1, R2.1, R2-USB.2, R2-USB1.1, R2_BAT.1, R4.1, RESET_BUTTON.1, RESET_BUTTON.2, SENSOR2.1 (GND), SENSOR2.5 (SDO), SENSOR2.7 (GND), SJ1.1, U1.4 (GND), U1.9 (EXP), U2.1 (GND), U2.28 (GND), U2.29_1 (GND), U2.29_2 (GND), U2.29_3 (GND), U2.29_4 (GND), U2.29_5 (GND), U2.29_6 (GND), U2.29_7 (GND), U2.29_8 (GND), U2.29_9 (GND), U3.13 (GND), U4.1 (CTG), U4.4 (GND), U4.6 (QSTRT), U4.9 (EP); also elsewhere on the board
GPIO8: R1.1, U2.10 (IO8)
I2C_PW: C1.1, C2.1, R1_PINH.2, R2_PINH.2, SENSOR2.2 (CSB), SENSOR2.6 (VDDIO), SENSOR2.8 (VDD), U2.17 (IO19)
INT_RTC: INT_RTC.TP, R1_PINH1.1, U2.8 (IO0), U3.3 (SQW/!INT)
IO/BOOT: BOOT_BUTTON.3, BOOT_BUTTON.4, C6.1, R_BOOT.2, U2.15 (IO9)
IO/CHANGE: C10.1, CHANGE_BUTTON.3, CHANGE_BUTTON.4, R_CHANGE.2, U2.23 (IO15)
MISO: D12.1, J4.P7 (DAT0), MISO.TP, R8.1, U1.2 (DO(IO1)), U2.27 (IO2)
MOSI: D6.1, J1.14, J4.P3 (CMD), MOSI.TP, R7.1, U1.5 (DI(IO0)), U2.7 (IO7)
unnamed: C1_BAT1.1, D2.1 (CATHODE), IC4.1 (VIN), IC4.3 (CE), Q1.2 (S)
unnamed: C4.1, D3.2 (A), D4.1 (K)
unnamed: J2.B5, R2-USB.1
unnamed: J2.A5, R2-USB1.2
unnamed: CHG_LED.C, R1-BAT.1
unnamed: MCP73831.1 (STAT), R1-BAT.2
unnamed: EPD_C12.1, J1.24
unnamed: MCP73831.5 (PROG), R2_BAT.2
unnamed: C_DELAY.1, IC1.5 (CT)
unnamed: D7.1 (CATHODE), R_CAPACITOR.1
unnamed: EPD_C10.1, J1.22
unnamed: EPD_C8.1, J1.20
unnamed: EPD_C7.1, J1.19
unnamed: EPD_C6.1, J1.18
unnamed: EPD_C2.1, J1.5
unnamed: EPD_C1.1, J1.4
unnamed: D6.2, D8.2, D9.2, D10.2, D11.2, D12.2
RESE: J1.3, Q3.2 (S), R3.2
RESE': R2.2, R3.1, SJ1.2
RESET: C5.1, IC1.1 (VOUT), RESET_BUTTON.3, RESET_BUTTON.4, R_RESET.2, U2.3 (EN)
RTC_RST: U2.16 (IO18), U3.4 (!RST)
RX: RX.TP, U2.24 (RXD0/GPIO17)
SCK: D8.1, J1.13, J4.P5 (CLK), R6.1, SCK.TP, U1.6 (CLK), U2.6 (IO6)
SCL: J3.4, R2_PINH.1, SENSOR2.4 (SCK), U2.20 (IO22), U3.16 (SCL), U4.7 (SCL)
SDA: J3.3, R1_PINH.1, SENSOR2.3 (SDI), U2.19 (IO21), U3.15 (SDA), U4.8 (SDA)
SRC: C4.2, D5.2 (A), L1.1, Q3.3 (D)
SS_SD: D11.1, J4.P2 (CD/DAT3), R10.1, U2.4 (IO4)
TX: TX.TP, U2.25 (TXD0/GPIO16)
USB_D+: D1.1 (I/O1_1), U2.14 (IO13)
USB_D-: D1.3 (I/O2_1), U2.13 (IO12)
VBAT: C2_BAT.1, MCP73831.3 (VBAT), Q1.3 (D), U4.2 (CELL), U4.3 (VDD), VBAT.TP
VBUS: C1_BAT.1, C4_USB.1, C5_USB.1, CHG_LED.A, D1.5 (VBUS), D2.2 (ANODE), MCP73831.4 (VIN), PFMF.050.1.2, Q1.1 (G), R1_PWRUSB.2, VBUS.TP
VRTC: C8.1, C10_SUPERCAP.2, R_CAPACITOR.2, U3.14 (VBAT)
VUSB: J2.A4, J2.A9, J2.B4, J2.B9, PFMF.050.1.1

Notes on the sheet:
USB C connector & ESD protection
LDO Voltage Regulator
SD Card
ESP32 C6
Battery ChargeLevel
External NOR Flash 64MB
SPI ESD Protection Lines
Qwiic / Stemma QT
Test Pads
RTC Module DS3231SN
Voltage Supervisor + Reset & Boot / IO Button
Environmental Sensor BME688
EPD Power
E-Paper Display Header
Li-Po Battery Charging Controller
E-Paper Drive Circuit
Display Type Selector
OpenBook Schematic
drawn by: Vasilica Danțiș

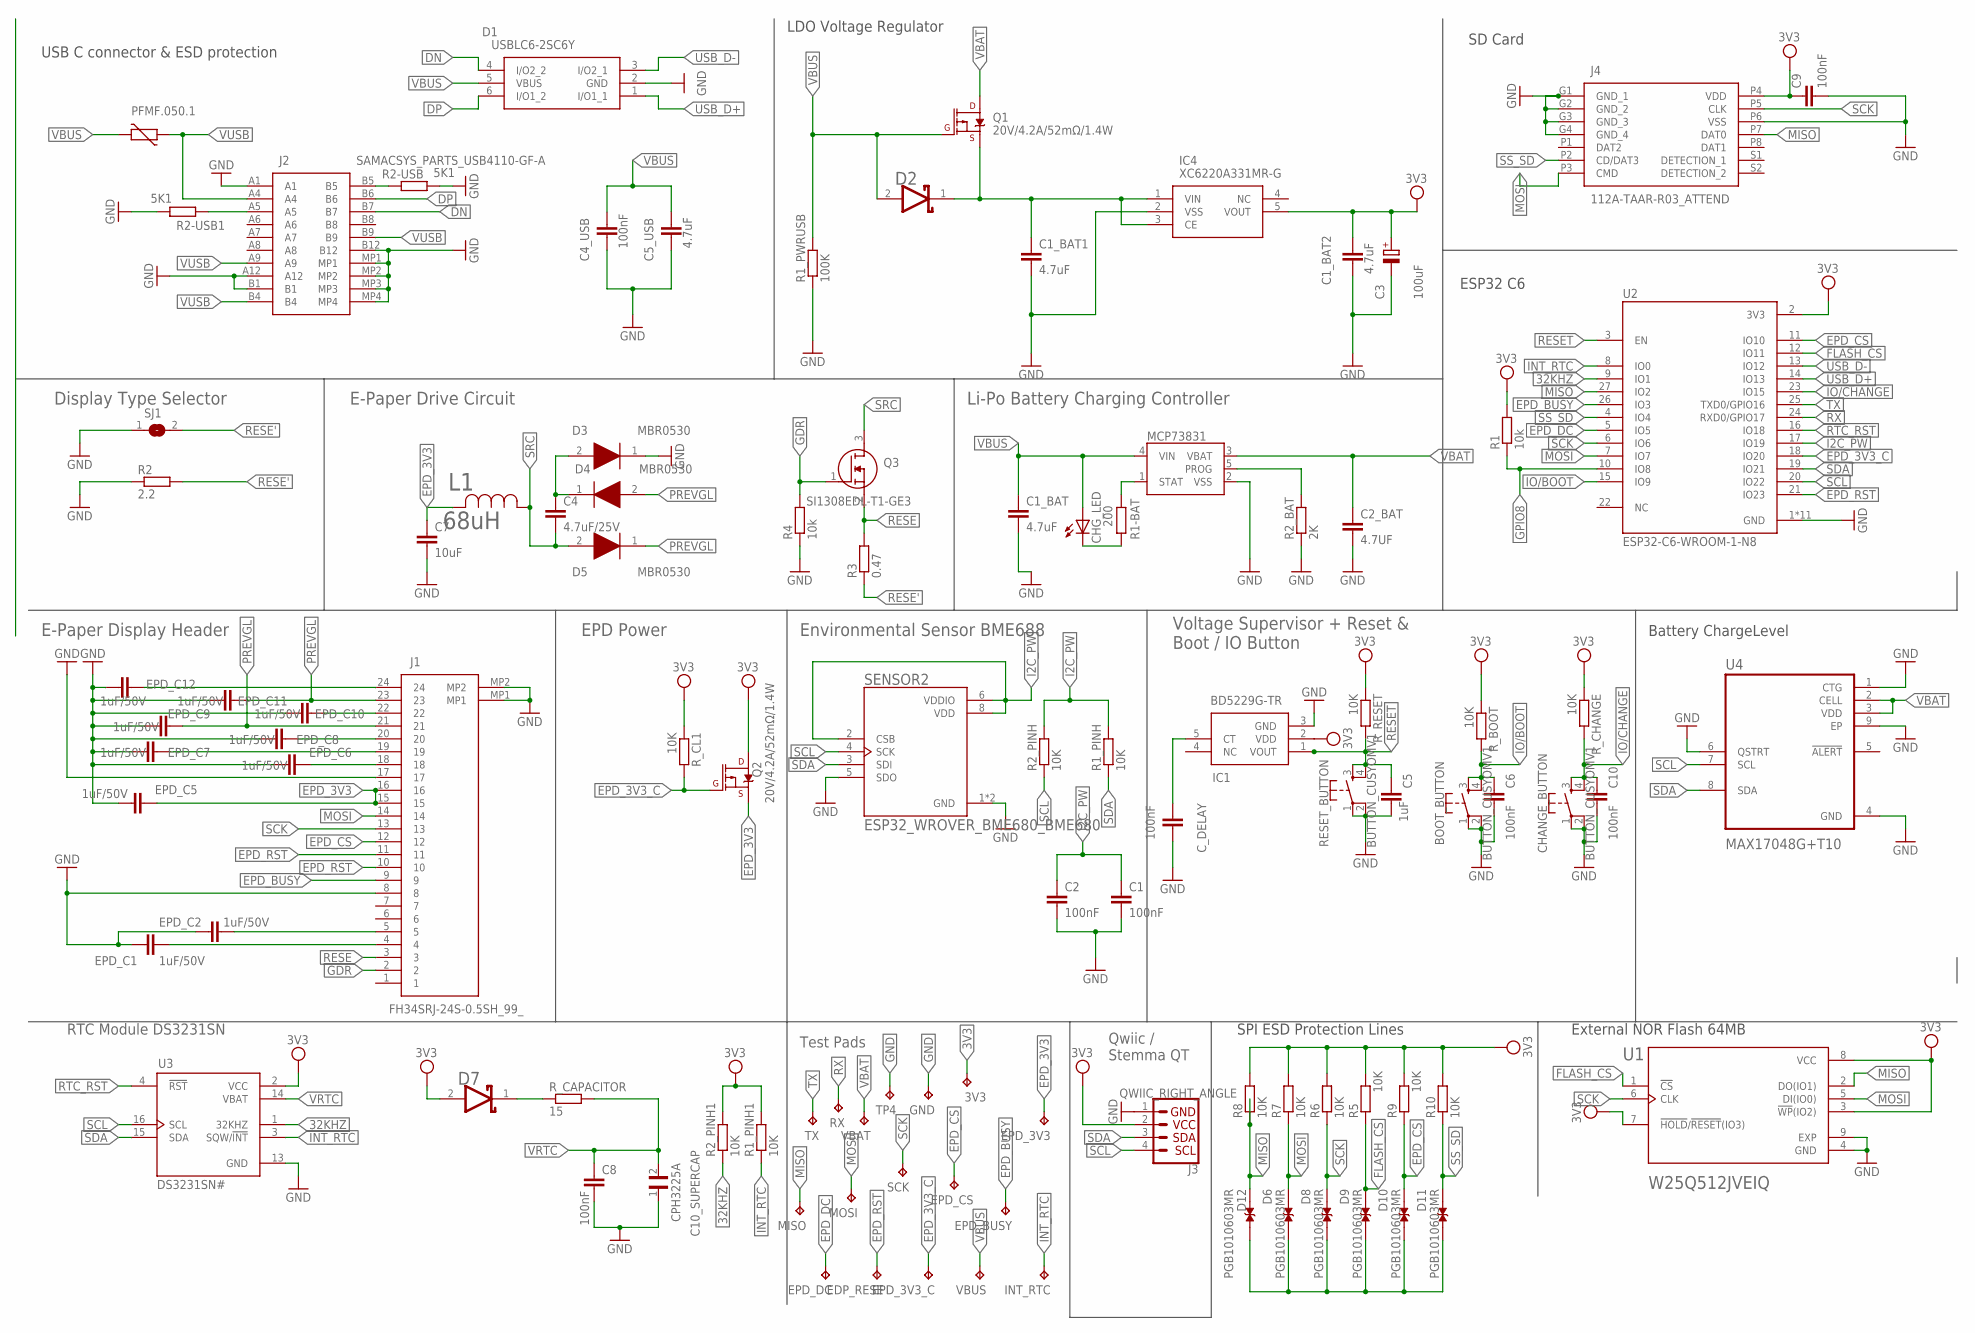
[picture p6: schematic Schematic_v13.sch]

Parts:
3V3: TPTP20R; TP20R
BOOT_BUTTON: BUTTON_CUSYOMV1; MYBUTTON
C1, C2, C4_USB, C6, C8, C9, C10: 100nF; ESP32_WROVER_EAGLE-LTSPICE_C0402
C1_BAT, C1_BAT1, C1_BAT2, C5_USB: 4.7uF; ESP32_WROVER_EAGLE-LTSPICE_C0402
C2_BAT: 4.7UF; ESP32_WROVER_EAGLE-LTSPICE_C0402
C3: 100uF; RCL_CT3528
C4: 4.7uF/25V; ESP32_WROVER_EAGLE-LTSPICE_C0402
C5: 1uF; ESP32_WROVER_EAGLE-LTSPICE_C0402
C7: 10uF; ESP32_WROVER_EAGLE-LTSPICE_C0402
C10_SUPERCAP: CPH3225A; CAPCP3225X100N
CHANGE_BUTTON: BUTTON_CUSYOMV1; MYBUTTON
CHG_LED: ADAFRUIT_LEDCHIP-LED0603; ADAFRUIT_CHIP-LED0603
C_DELAY: 100nF; ESP32_WROVER_EAGLE-LTSPICE_C0402
D1: USBLC6-2SC6Y; SOT95P280X145-6N
D2, D7: ESP32_WROVER_AVX---SD0805S020S1R0_AVX_SD0805S020S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; ESP32_WROVER_AVX---SD0805S020S1R0_AVX_SD0805S020S1R0_0
D3, D4, D5: MBR0530; SOD3716X135N
D6, D8, D9, D10, D11, D12: PGB1010603MR; DIOC1608X36N
EDP_RESE: TPTP20R; TP20R
EPD_3V3, EPD_3V3_C: TPTP20R; TP20R
EPD_BUSY: TPTP20R; TP20R
EPD_C1, EPD_C2, EPD_C5, EPD_C6, EPD_C7, EPD_C8, EPD_C9, EPD_C10, EPD_C11, EPD_C12: 1uF/50V; ESP32_WROVER_EAGLE-LTSPICE_C0402
EPD_CS: TPTP20R; TP20R
EPD_DC: TPTP20R; TP20R
GND: TPTP20R; TP20R
IC1: BD5229G-TR; SOT95P280X120-5N
IC4: XC6220A331MR-G; SOT95P280X120-5N
INT_RTC: TPTP20R; TP20R
J1: FH34SRJ-24S-0.5SH_99_; FH34SRJ24S05SH99
J2: SAMACSYS_PARTS_USB4110-GF-A; SAMACSYS_PARTS_USB4110GFA
J3: QWIIC_RIGHT_ANGLE; JST04_1MM_RA
J4: 112A-TAAR-R03_ATTEND; 112ATAARR03ATTEND
L1: 68uH; IND_4828-WE-TPC_WRE
MCP73831: ESP32_WROVER_SPARKFUN-IC-POWER_MCP73831; ESP32_WROVER_SPARKFUN-IC-POWER_SOT23-5
MISO: TPTP20R; TP20R
MOSI: TPTP20R; TP20R
PFMF.050.1: ESP32C6_VARISTORCN1812; ESP32C6_VARISTOR_CT/CN1812
Q1, Q2: 20V/4.2A/52mΩ/1.4W; ESP32_WROVER_SPARKFUN-DISCRETESEMI_SOT23-3
Q3: SI1308EDL-T1-GE3; SOT65P210X110-3N
R1, R4: 10k; ESP32_WROVER_EAGLE-LTSPICE_R0402
R1-BAT: 200; ESP32_WROVER_EAGLE-LTSPICE_R0402
R1_PINH, R1_PINH1, R2_PINH, R2_PINH1, R5, R6, R7, R8, R9, R10: 10K; ESP32_WROVER_EAGLE-LTSPICE_R0402
R1_PWRUSB: 100K; ESP32_WROVER_EAGLE-LTSPICE_R0402
R2: 2.2; ESP32_WROVER_EAGLE-LTSPICE_R0402
R2-USB, R2-USB1: 5K1; ESP32_WROVER_EAGLE-LTSPICE_R0402
R2_BAT: 2K; ESP32_WROVER_EAGLE-LTSPICE_R0402
R3: 0.47; ESP32_WROVER_EAGLE-LTSPICE_R0402
RESET_BUTTON: BUTTON_CUSYOMV1; MYBUTTON
RX: TPTP20R; TP20R
R_BOOT: 10K; ESP32_WROVER_EAGLE-LTSPICE_R0402
R_CAPACITOR: 15; ESP32_WROVER_EAGLE-LTSPICE_R0402
R_CHANGE: 10K; ESP32_WROVER_EAGLE-LTSPICE_R0402
R_CL1: 10K; ESP32_WROVER_EAGLE-LTSPICE_R0402
R_RESET: 10K; ESP32_WROVER_EAGLE-LTSPICE_R0402
SCK: TPTP20R; TP20R
SENSOR2: ESP32_WROVER_BME680_BME680; ESP32_WROVER_BME680_PSON80P300X300X100-8N
SJ1: SJ
TP4: TPTP20R; TP20R
TX: TPTP20R; TP20R
U1: W25Q512JVEIQ; SON127P600X800X80-9N
U2: ESP32-C6-WROOM-1-N8; XCVR_ESP32-C6-WROOM-1-N8
U3: DS3231SN#; SOIC127P1032X265-16N
U4: MAX17048G+T10; SON50P200X200X80-9N
VBAT: TPTP20R; TP20R
VBUS: TPTP20R; TP20R

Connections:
3V3: 3V3.TP, C1_BAT2.1, C3.+, C9.1, D7.2 (ANODE), IC1.2 (VDD), IC4.5 (VOUT), J3.2, J4.P4 (VDD), Q2.3 (D), R1.2, R1_PINH1.2, R2_PINH1.2, R5.2, R6.2, R7.2, R8.2, R9.2, R10.2, R_BOOT.1, R_CHANGE.1, R_CL1.1, R_RESET.1, U1.3 (!WP!(IO2)), U1.7 (!HOLD!/!RESET!(IO3)), U1.8 (VCC), U2.2 (3V3), U3.2 (VCC)
32KHZ: R2_PINH1.1, U2.9 (IO1), U3.1 (32KHZ)
DN: D1.4 (I/O2_2), J2.B7; also elsewhere on the board
DP: D1.6 (I/O1_2), J2.B6; also elsewhere on the board
EPD_3V3: C7.1, EPD_3V3.TP, EPD_C5.1, J1.15, J1.16, L1.2, Q2.2 (S)
EPD_3V3_C: EPD_3V3_C.TP, Q2.1 (G), R_CL1.2, U2.18 (IO20)
EPD_BUSY: EPD_BUSY.TP, J1.9, U2.26 (IO3)
EPD_CS: D10.1, EPD_CS.TP, J1.12, R9.1, U2.11 (IO10)
EPD_DC: EPD_DC.TP, U2.5 (IO5)
EPD_RST: EDP_RESE.TP, J1.10, J1.11, U2.21 (IO23)
FLASH_CS: D9.1, R5.1, U1.1 (!CS), U2.12 (IO11)
GDR: J1.2, Q3.1 (G), R4.2
GND: BOOT_BUTTON.1, BOOT_BUTTON.2, C1.2, C1_BAT.2, C1_BAT1.2, C1_BAT2.2, C2.2, C2_BAT.2, C3.-, C4_USB.2, C5.2, C5_USB.2, C6.2, C7.2, C8.2, C9.2, C10.2, C10_SUPERCAP.1, CHANGE_BUTTON.1, CHANGE_BUTTON.2, C_DELAY.2, D1.2 (GND), D3.1 (K), EPD_C1.2, EPD_C2.2, EPD_C5.2, EPD_C6.2, EPD_C7.2, EPD_C8.2, EPD_C9.2, EPD_C10.2, EPD_C11.2, EPD_C12.2, GND.TP, IC1.3 (GND), IC4.2 (VSS), J1.8, J1.17, J1.MP1, J1.MP2, J2.A1, J2.A12, J2.B1, J2.B12, J2.MP1, J2.MP2, J2.MP3, J2.MP4, J3.1, J4.G1 (GND_1), J4.G2 (GND_2), J4.G3 (GND_3), J4.G4 (GND_4), J4.P6 (VSS), MCP73831.2 (VSS), R1_PWRUSB.1, R2.1, R2-USB.2, R2-USB1.1, R2_BAT.1, R4.1, RESET_BUTTON.1, RESET_BUTTON.2, SENSOR2.1 (GND), SENSOR2.5 (SDO), SENSOR2.7 (GND), SJ1.1, TP4.TP, U1.4 (GND), U1.9 (EXP), U2.1 (GND), U2.28 (GND), U2.29_1 (GND), U2.29_2 (GND), U2.29_3 (GND), U2.29_4 (GND), U2.29_5 (GND), U2.29_6 (GND), U2.29_7 (GND), U2.29_8 (GND), U2.29_9 (GND), U3.13 (GND), U4.1 (CTG), U4.4 (GND), U4.6 (QSTRT), U4.9 (EP); also elsewhere on the board
GPIO8: R1.1, U2.10 (IO8)
I2C_PW: C1.1, C2.1, R1_PINH.2, R2_PINH.2, SENSOR2.2 (CSB), SENSOR2.6 (VDDIO), SENSOR2.8 (VDD), U2.17 (IO19)
INT_RTC: INT_RTC.TP, R1_PINH1.1, U2.8 (IO0), U3.3 (SQW/!INT)
IO/BOOT: BOOT_BUTTON.3, BOOT_BUTTON.4, C6.1, R_BOOT.2, U2.15 (IO9)
IO/CHANGE: C10.1, CHANGE_BUTTON.3, CHANGE_BUTTON.4, R_CHANGE.2, U2.23 (IO15)
MISO: D12.1, J4.P7 (DAT0), MISO.TP, R8.1, U1.2 (DO(IO1)), U2.27 (IO2)
MOSI: D6.1, J1.14, J4.P3 (CMD), MOSI.TP, R7.1, U1.5 (DI(IO0)), U2.7 (IO7)
unnamed: C1_BAT1.1, D2.1 (CATHODE), IC4.1 (VIN), IC4.3 (CE), Q1.2 (S)
unnamed: C4.1, D3.2 (A), D4.1 (K)
unnamed: J2.B5, R2-USB.1
unnamed: J2.A5, R2-USB1.2
unnamed: CHG_LED.C, R1-BAT.1
unnamed: MCP73831.1 (STAT), R1-BAT.2
unnamed: EPD_C12.1, J1.24
unnamed: MCP73831.5 (PROG), R2_BAT.2
unnamed: C_DELAY.1, IC1.5 (CT)
unnamed: D7.1 (CATHODE), R_CAPACITOR.1
unnamed: EPD_C10.1, J1.22
unnamed: EPD_C8.1, J1.20
unnamed: EPD_C7.1, J1.19
unnamed: EPD_C6.1, J1.18
unnamed: EPD_C2.1, J1.5
unnamed: EPD_C1.1, J1.4
unnamed: D6.2, D8.2, D9.2, D10.2, D11.2, D12.2
RESE: J1.3, Q3.2 (S), R3.2
RESE': R2.2, R3.1, SJ1.2
RESET: C5.1, IC1.1 (VOUT), RESET_BUTTON.3, RESET_BUTTON.4, R_RESET.2, U2.3 (EN)
RTC_RST: U2.16 (IO18), U3.4 (!RST)
RX: RX.TP, U2.24 (RXD0/GPIO17)
SCK: D8.1, J1.13, J4.P5 (CLK), R6.1, SCK.TP, U1.6 (CLK), U2.6 (IO6)
SCL: J3.4, R2_PINH.1, SENSOR2.4 (SCK), U2.20 (IO22), U3.16 (SCL), U4.7 (SCL)
SDA: J3.3, R1_PINH.1, SENSOR2.3 (SDI), U2.19 (IO21), U3.15 (SDA), U4.8 (SDA)
SRC: C4.2, D5.2 (A), L1.1, Q3.3 (D)
SS_SD: D11.1, J4.P2 (CD/DAT3), R10.1, U2.4 (IO4)
TX: TX.TP, U2.25 (TXD0/GPIO16)
USB_D+: D1.1 (I/O1_1), U2.14 (IO13)
USB_D-: D1.3 (I/O2_1), U2.13 (IO12)
VBAT: C2_BAT.1, MCP73831.3 (VBAT), Q1.3 (D), U4.2 (CELL), U4.3 (VDD), VBAT.TP
VBUS: C1_BAT.1, C4_USB.1, C5_USB.1, CHG_LED.A, D1.5 (VBUS), D2.2 (ANODE), MCP73831.4 (VIN), PFMF.050.1.2, Q1.1 (G), R1_PWRUSB.2, VBUS.TP
VRTC: C8.1, C10_SUPERCAP.2, R_CAPACITOR.2, U3.14 (VBAT)
VUSB: J2.A4, J2.A9, J2.B4, J2.B9, PFMF.050.1.1

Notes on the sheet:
USB C connector & ESD protection
LDO Voltage Regulator
SD Card
ESP32 C6
Battery ChargeLevel
External NOR Flash 64MB
SPI ESD Protection Lines
Qwiic / Stemma QT
Test Pads
RTC Module DS3231SN
Voltage Supervisor + Reset & Boot / IO Button
Environmental Sensor BME688
EPD Power
E-Paper Display Header
Li-Po Battery Charging Controller
E-Paper Drive Circuit
Display Type Selector

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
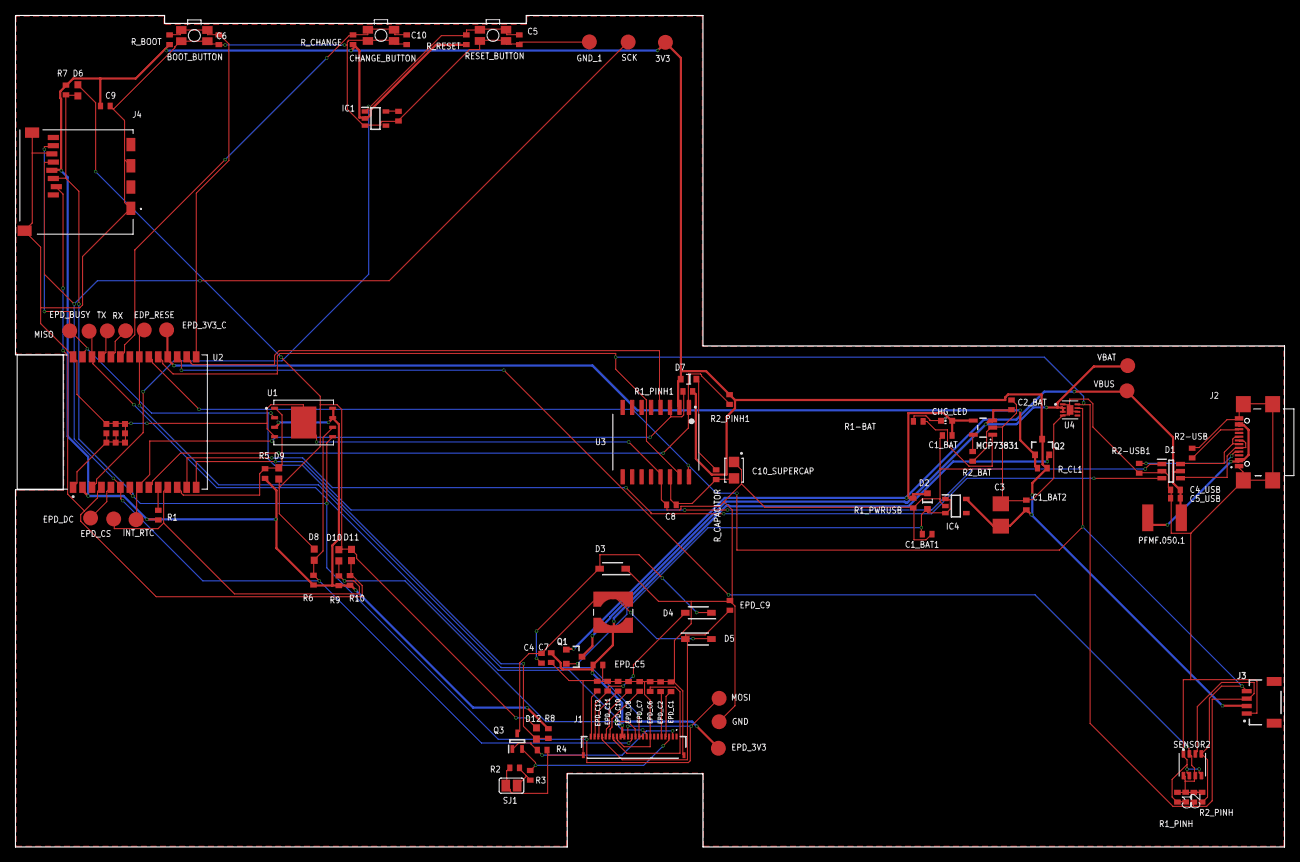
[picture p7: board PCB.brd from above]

Board: 2 copper layers, 170.2 x 111.5 mm, 103 parts (0 on the bottom side), 56 nets.

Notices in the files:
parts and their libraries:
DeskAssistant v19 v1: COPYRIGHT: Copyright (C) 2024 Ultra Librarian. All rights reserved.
